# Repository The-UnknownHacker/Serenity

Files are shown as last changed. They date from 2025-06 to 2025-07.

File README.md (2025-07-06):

# Serenity

**Serenity** is a drumpad or macropad designed with musicians in mind.  
Instead of using traditional switches or buttons, it uses a **copper layer on the PCB** to detect touch input.

Powered by an **ESP32-S3 devkit**, Serenity can store sound files on a **microSD card** and output audio through a **headphone jack**.

It features **2 configurable buttons** that let you switch between sound "layers" — allowing you to play many more sounds than just 8.  
For example, with 4 layers, you can trigger **32 unique sounds**.

---

I built **Serenity** after being inspired by those expensive drumpads used for triggering sound effects.  
They often cost a fortune, so I created **Serenity** to cost **under $50 USD**, without sacrificing creativity or functionality.
=======

Images

-------------
Schematic



PCB



3D Model



BOM

| Designator | Footprint | Quantity | Value | LCSC Part # | Purchase Method | Est. Price (USD) |
|---|---|---|---|---|---|---|
| C1 | 1812 | 1 | 100nf | https://lcsc.com/product-detail/Multilayer-Ceramic-Capacitors-MLCC-SMD-SMT_TDK_C342613.html | PCBA | $0.34 |
| J1 | microSD_HC_Molex_47219-2001 | 1 | Micro_SD_Card | https://lcsc.com/product-detail/SD-Card-Memory-Card-Connector_MOLEX-472192001_C164170.html | PCBA | $0.48 |
| J2 | HRO_PJ-320D-A | 1 | PJ-320D-A | https://lcsc.com/product-detail/_Korean-Hroparts-Elec-PJ-320D-4A_C95562.html | PCBA | $1.50* |
| SW1, SW2 | SW_PUSH-12mm_Wuerth-430476085716 | 2 | SW_Push | https://www.adafruit.com/product/1119?srsltid=AfmBOoqwRE8KhgtdWcEbSr0UxHVauoeQpAy56lpgwJ67pl_6lD0DS_sJ | Ordering Online | $2.50* |
| U1 | ESP32-S2-DevKitC-1 | 1 | ESP32-S3-DevKitC | https://www.aliexpress.com/item/1005006446406795.html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 | Ordering Online | $10.00 |
| U2 | TQFN-16-1EP_3x3mm_P0.5mm_EP1.23x1.23mm | 1 | MAX98357A | https://lcsc.com/product-detail/Audio-Amplifiers_Analog-Devices-Inc-Maxim-Integrated-MAX98357AETE-T_C910544.html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 | PCBA | $3.50* |

## Total Estimated Cost
**Subtotal: ~$50 USD** without shipping

- Prices dont include shipping, taxes, and PCBA assembly fees
- PCBA components might have additional assembly costs

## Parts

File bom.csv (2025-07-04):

Designator | Footprint | Quantity | Value | LCSC Part # | Purchase Method
C1 | 1812 | 1 | 100nf | https://lcsc.com/product-detail/Multilayer-Ceramic-Capacitors-MLCC-SMD-SMT_TDK_C342613.html | PCBA
J1 | microSD_HC_Molex_47219-2001 | 1 | Micro_SD_Card | https://lcsc.com/product-detail/SD-Card-Memory-Card-Connector_MOLEX-472192001_C164170.html | PCBA
J2 | HRO_PJ-320D-A | 1 | PJ-320D-A | https://lcsc.com/product-detail/_Korean-Hroparts-Elec-PJ-320D-4A_C95562.html | PCBA
SW1, SW2 | SW_PUSH-12mm_Wuerth-430476085716 | 2 | SW_Push | https://www.adafruit.com/product/1119 | Ordering Online
U1 | ESP32-S2-DevKitC-1 | 1 | ESP32-S3-DevKitC | https://www.altronics.com.au/p/z6433-esp-32s3-development-board/ | Going Inshore (Local Shop)
U2 | TQFN-16-1EP_3x3mm_P0.5mm_EP1.23x1.23mm | 1 | MAX98357A | https://lcsc.com/product-detail/Audio-Amplifiers_Analog-Devices-Inc-Maxim-Integrated-MAX98357AETE-T_C910544.html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

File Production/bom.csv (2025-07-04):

Designator | Footprint | Quantity | Value | LCSC Part #
C1 | 1812 | 1 | 100nf
J1 | microSD_HC_Molex_47219-2001 | 1 | Micro_SD_Card
J2 | HRO_PJ-320D-A | 1 | PJ-320D-A
SW1, SW2 | SW_PUSH-12mm_Wuerth-430476085716 | 2 | SW_Push
U1 | ESP32-S2-DevKitC-1 | 1 | ESP32-S3-DevKitC
U2 | TQFN-16-1EP_3x3mm_P0.5mm_EP1.23x1.23mm | 1 | MAX98357A

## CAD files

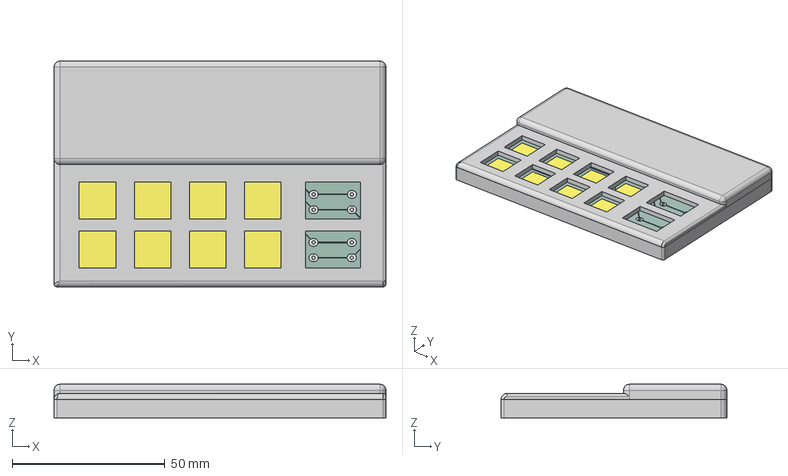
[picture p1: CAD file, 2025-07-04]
CAD/Serenity v1.step
108.5 x 73.8 x 11.0 mm
C_1812_4532Metric
Serenity_copper
Serenity_pad
Serenity_via
Serenity_PCB

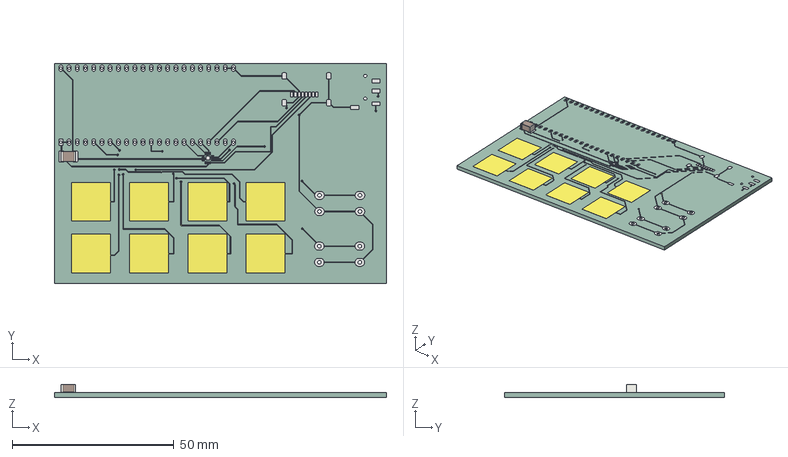
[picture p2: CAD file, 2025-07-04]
PCB/Serenity_PCB.step
102.6 x 68.1 x 4.13 mm
C_1812_4532Metric
Serenity_copper
Serenity_pad
Serenity_via
Serenity_PCB

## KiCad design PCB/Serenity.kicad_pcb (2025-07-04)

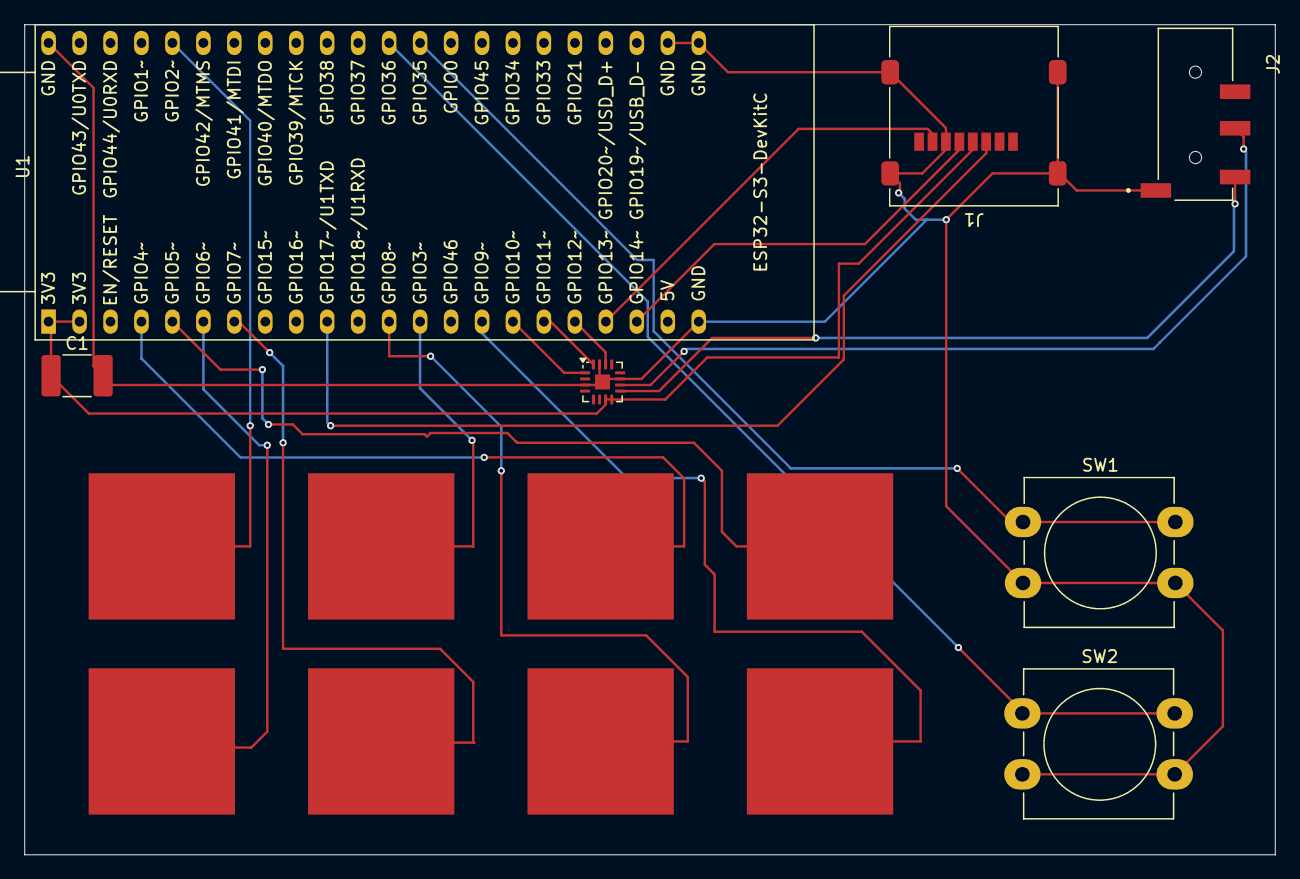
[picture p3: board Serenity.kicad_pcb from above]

Board: 2 copper layers, 102.6 x 68.1 mm, 7 parts (0 on the bottom side), 12 nets.

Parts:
C1: 100nf; C_1812_4532Metric_Pad1.57x3.40mm_HandSolder
J1: Micro_SD_Card; microSD_HC_Molex_47219-2001
J2: PJ-320D-A; HRO_PJ-320D-A
SW1, SW2: SW_Push; SW_PUSH-12mm_Wuerth-430476085716
U1: ESP32-S3-DevKitC; ESP32-S2-DevKitC-1
U2: MAX98357A; TQFN-16-1EP_3x3mm_P0.5mm_EP1.23x1.23mm

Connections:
BCLK: U1.17 (GPIO11/ADC2_CH0), U2.16 (BCLK)
CLK: J1.5 (CLK), U1.20 (GPIO14/ADC2_CH3)
CMD: J1.3 (CMD), U1.10 (GPIO17/ADC2_CH6)
DAT0: J1.7 (DAT0), U1.19 (GPIO13/ADC2_CH2)
DIN: U1.16 (GPIO10/ADC1_CH9), U2.1 (DIN)
GPIO35: SW1.1, U1.32 (GPIO35)
GPIO36: SW2.1, U1.33 (GPIO36)
LRCLK: U1.18 (GPIO12/ADC2_CH1), U2.14 (LRCLK)
RING: J2.3, U2.10 (OUTN)
TIP: J2.2, U2.9 (OUTP)
VDD: C1.1, J1.4 (VDD), U1.1 (3V3), U1.2 (3V3), U2.7 (VDD), U2.8 (VDD)
VSS: C1.2, J1.6 (VSS), J1.9 (SHIELD), J2.1, SW1.2, SW2.2, U1.22 (GND), U1.23 (GND), U1.24 (GND), U1.44 (GND), U2.3 (GND), U2.11 (GND), U2.15 (GND), U2.17 (PAD)

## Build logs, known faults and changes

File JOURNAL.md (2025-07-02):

---
Title: "Serenity"
Author: "Aarav J"
Description: "Serenity is a drumpad that uses copper touch panels!"
Created_On: "24/6/2025"
---

# June 24th: Started choosing components and integrating them with the PCB

I started to choose the components that I am going to use - /
First I decided on using the Xiao ESP32-s3 board but now I might use a normal ESP32-s3 devboard as I need more gpio
The parts I have decided for now are

- ESP32-s3 devboard
- Micro SD Card Slot
- Headphone Jack
- MAX98357A Audio DAC
- Everything will be powered by the ESP's USB C port

I also started to wire up most of the circuit and I think I have finished the first version of the schematic. 
This is a rough schematic and I will need to double check if it fully works or not.
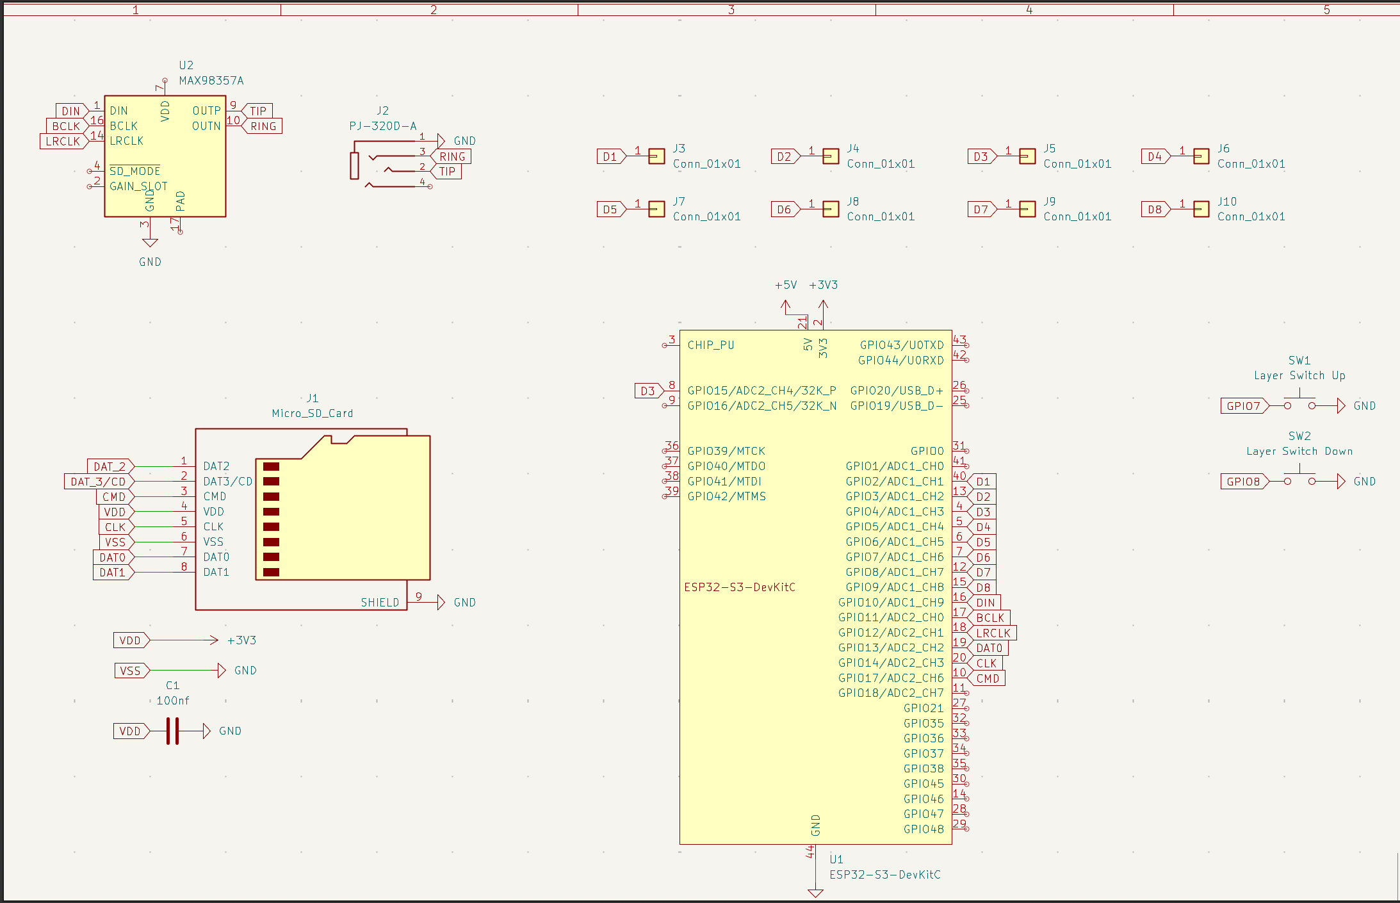
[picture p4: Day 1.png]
Day 1


**Total time spent: 8h**

# June 26th : Assigned some of the footprints and started the PCB with rough routing

Today I started a rough PCB design and diagram to visualize the basic design.
As of now my design is still missing key resisistors and capacitors and is not in working shape just yet (just a mockup)

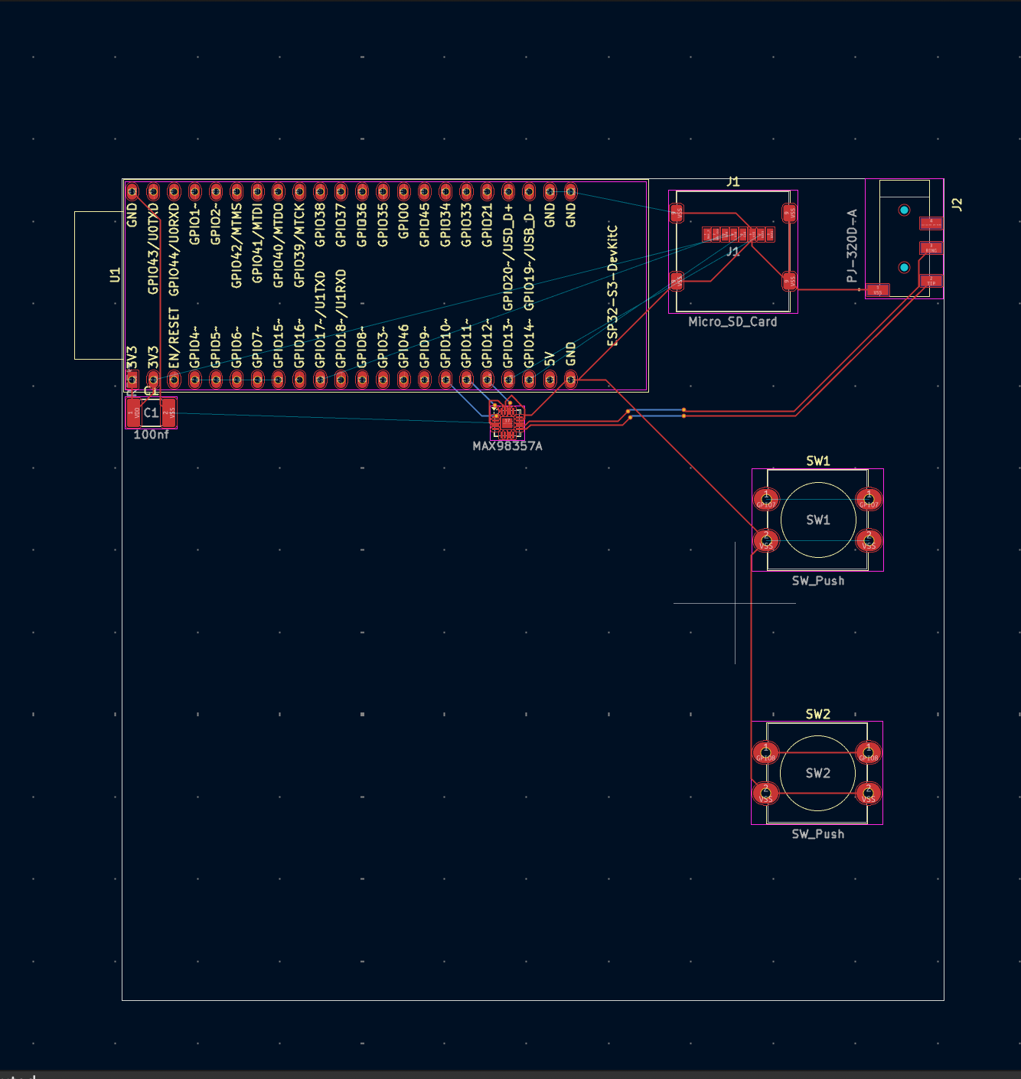
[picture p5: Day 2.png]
Day 2


**Total time spent: 4h**

# June 28th : Assigned all the footprints and finished the PCB outline

Today I finished choosing all my parts and assignigning all the footprints + alignment. I then alligned all the parts on the PCB and chose a design. 

I had some difficulty in getting the copper pad loaded onto the PCB but I figured out that I can import a black square into kicads image translator and then convert that to a footprint. From there I can then draw out a trace from the copper pad and assign the net to one of the digital connector pins on the ESP32.

At the end I ended up with something like this


And for the PCB



Now it was time to begin the routing 😭

I spent a good 2 hours on this and it was fairly challenging as I had to be careful with the copper pads and not to short anything



After running a DRC it showed a couple errors relating to the trace shorting a pad. This is a known error and isnt a problem as the trace NEEDS to short the pad to make a connection. Otherwise the PCB is fully clear. At the start I experienced a trace cutoff error meaning that the trace was too close to the edge of the board and this was fixed by just extending the board length



**Total time spent: 6h**

# July 2nd : Started and finished CAD

Today I started and finished the CAD design
To start I need to export the STEP file from KiCad (PCB Editor) to fusion. This allows me to accurately get the dimensions of the PCB and design appropriately.
Once in KiCad I can click on file and then export as step and be brought to this window


I left the settings as default and exported the STEP File
After importing it into fusion it looks something like this



After importing the PCB I can create a base outline around it that looks something like this



Here is the base with the PCB



I then created an outline for the top roof housing the ESP and holes for the pads



Here is the roof with the PCB



And finally here is the completed case



Now after building all of this I realised I made a crucial mistake. I left out the holes for the layer switch buttons here



To fix this I just created another sketch and ended up with something like this



After that I added Fillets to everything to round everything and was left with something like this



After this I realised I also forgot the holes for the ESP and headphone jack so I created a simple hole sketch like so



After extruding I was left with something like this



I can the fillet everything to get a nice rounded finish



I repeated the same steps for the headphone jack and SD card and was left with the finished case





Thats it!, The entire case + PCB is complete! To print it since it has holes it is made in 2 parts to glue together so it requires minimum supports!
